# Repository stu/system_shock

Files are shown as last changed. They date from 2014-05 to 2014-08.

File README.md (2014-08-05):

System Shock
============
System Shock is an Open Source Pinball controller system consisting of hardware schematics and source code to drive the system.

The design goal is a board set capable of;

* 128 switches
* 32 solenoids / flashers
* LCD display
* Stero Sound

The last two can be achieved by utilising a Raspberry PI or some other small embedded computer.

Current Status
==============
*This is a very early work in progress that requires a lot more testing and design review.*

Licenses
========
### Software
All software and documentation is licensed under the GNU GPL v2
(see ./gpl-v2.txt)

### Hardware
All hardware schematics are licensed under the CERN Open Hardware License v1.2
(see cern_ohl_v_1_2.txt)

Revision History
================
### 20140805
* Tagged revision 1 of the solenoid board as I sent it to the fab to get made

### 20140605
* Rerouted solenoid driver board
* Exported gerbers + Excellon drill file for solenoid driver

### 20140524

* Expose to github
* Copy solenoid driver code and schematics over
* Hack up parts of master document into solenoid documentation

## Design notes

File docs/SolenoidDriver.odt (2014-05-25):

# Solenoid Driver

Last Edit; 20140524

## Introduction

The Solenoid driver consists of two parts, a hardware schematic in DipTrace and the software component that runs on the propeller microcontroller.

The schematic for the solenoid driver is under the CERN Open Hardware license v1.2

The source code for the solenoid driver is under the GNU GPL v2

## Hardware Overview

The goal of the solenoid is to control the high voltage power (solenoids, flashers, motors, etc). We are using the lower voltage of the microcontroller at 3.3v. We control the high power basically using an MOSFET driver (MCP1407) and an IRF640 MOSFET. This achieves low side switching (low side switching is where power (+) is continually run to the device (eg: solenoid), and when the solenoid driver closes the circuit and connects the ground (GND or -).

Low side switching as we are doing, is much easier to achieve than High side switching (where you continually connect GND and only connect the + as needed).

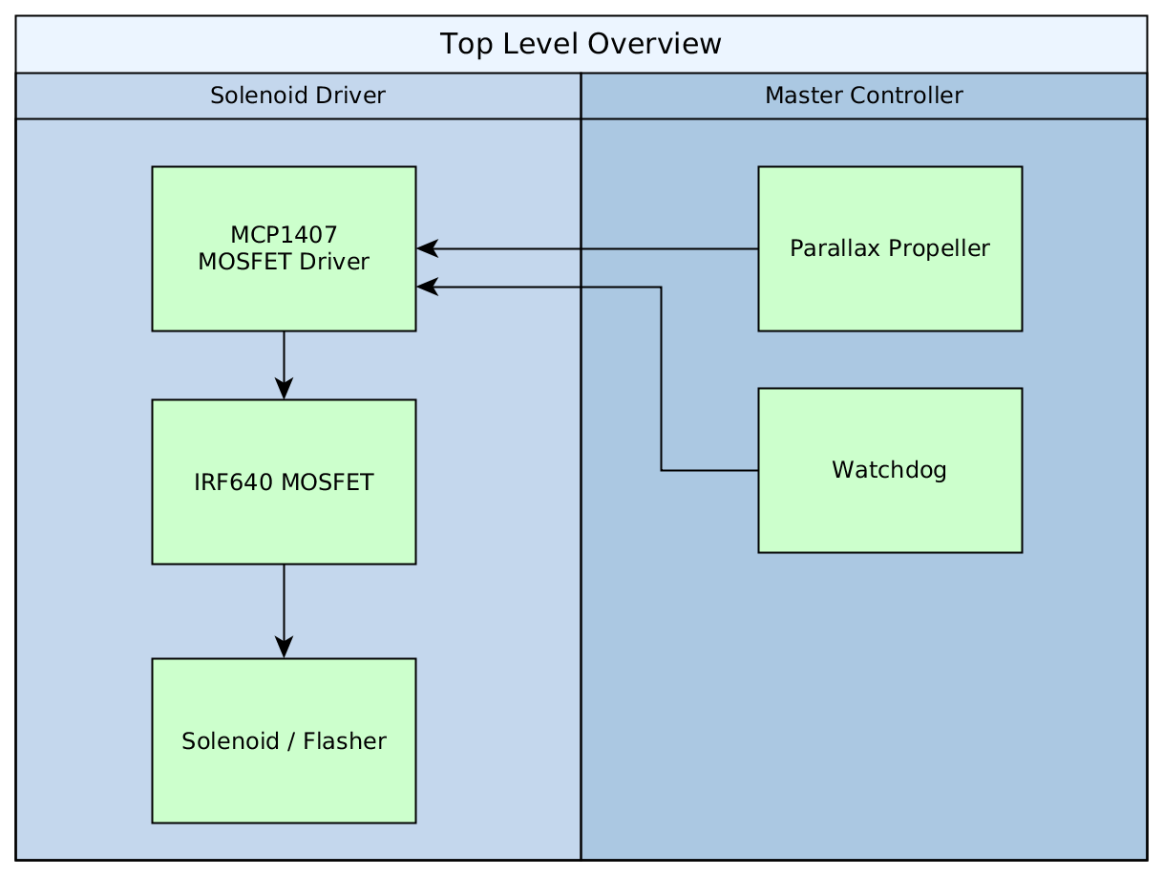
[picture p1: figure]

The propeller does the timings of all the 32 solenoids, it works in conjunction with the watchdog. The idea of the watchdog is to look over the propeller and make sure its not locked up. If the propeller locks up, the watchdog cuts off power to all the solenoids so things do not burn up and lock on.

The propeller has 8 internal cores that run simultaneously. We use core 0 to read 32 switch inputs from the Master Control board, as well as send the 32 outputs to the shift register chips that connect directly to the MOSFET Drivers. We use cores 1 thru 7 to do all the timings, they each time 5 solenoids, with the last timing just 2 to round us to 32 in total.

The propeller outputs to a bank of 4 shift registers, that are also tied directly to the watchdog output.

## Software

The source code has been written for compilation with the PropGCC compiler, and has been designed to run completely inside its COG memory model (As small detour, the propeller has 3 or 4 memory models that PropGCC can use, if the code is small enough to fit inside the propellers cache, it can run as COG ram, if its larger than the memory space, it will be compiled into an intermediate byte code and retrieved from its EEPROM, this takes a substantial performance hit), it is also written to be lock free.

## Power

There are two different power requirements for the solenoid driver. There is the lower voltage 3.3VDC driving the shift registers, and the higher 12VDC voltage driving the FET drivers. The FET drivers use a higher voltage to pump the MOSFET into action.

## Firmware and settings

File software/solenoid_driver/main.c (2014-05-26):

#include <propeller.h>
#include <stdint.h>
#include <sys/thread.h>

#include "solenoid.h"

struct solenoid_mailbox cogdata[7];

// configuration set over the wire by the master control board
HUBDATA volatile uint32_t initial_pulse_time_min[MAX_SOL];
HUBDATA volatile uint32_t initial_pulse_time_max[MAX_SOL];
HUBDATA volatile uint32_t pulse_pause_time[MAX_SOL];
HUBDATA volatile uint32_t pulse_hold_time[MAX_SOL];

// These change each time coils fire
HUBDATA volatile uint32_t state[MAX_SOL];
HUBDATA volatile uint32_t power_on_ms[MAX_SOL];
HUBDATA volatile uint32_t cnt_start[MAX_SOL];

// each cog gets its own variable so we can go lockless
HUBDATA volatile uint32_t solenoid_pins0;
HUBDATA volatile uint32_t solenoid_pins1;
HUBDATA volatile uint32_t solenoid_pins2;
HUBDATA volatile uint32_t solenoid_pins3;
HUBDATA volatile uint32_t solenoid_pins4;
HUBDATA volatile uint32_t solenoid_pins5;
HUBDATA volatile uint32_t solenoid_pins6;


/* cause all internal data state to reset */
#define CMD_RESET			0x01

/* This takes 4 bytes of 8bit data to setup */
#define CMD_SETUP_SOL		0x02

/* this takes 4x8bit data for 32 switch inputs */
#define CMD_SWITCHES		0x03


/*
 * These pins map as written in the data sheet.
 */

// direct message communication
#define COMMS_D1			0
#define COMMS_D2			1
#define COMMS_D3			2
#define COMMS_D4			3
#define COMMS_D5			4
#define COMMS_D6			5
#define COMMS_D7			6
#define COMMS_D8			7

#define COMMS_D9			8
#define COMMS_D10			9
#define COMMS_D11			10
#define COMMS_D12			11
#define COMMS_D13			12
#define COMMS_D14			13
#define COMMS_D15			14
#define COMMS_D16			15

#define RCV_PIN				27
#define RCV_OK				26

// solenoid outputs
#define HC595_CLK			16
#define HC595_DATA			17
#define HC595_LATCH			18
#define WATCHDOG			19

#define PIN_HIGH(a)		(OUTA |= (1 << (a)))
#define PIN_LOW(a)		(OUTA &= ~(1 << (a)))
#define READ_PIN(a)		(INA & (1 << (a)) )

/* Reads 16bits of data from PIC32 command.
 *
 * @blocking zero will wait until data arrives.
 */
static uint32_t read_command_word (int blocking)
{
	uint32_t data;

	// wait for rcv to go high for data is ready
	while (READ_PIN(RCV_PIN) == 0)
	{
		if (blocking != 0)
			return 0;
	}

	// get 16 bits and say we got it
	data = ((INA >> COMMS_D1) & 0xFFFF);
	PIN_HIGH(RCV_OK);

	// wait for RCV to go low
	while (READ_PIN(RCV_PIN) == 1)
		;

	// put OK low so we are ready for next communication
	PIN_LOW(RCV_OK);

	return data;
}

/* Resets all solenoid out data pins, and all internal data structures
 */
static void reset_data (void)
{
	int i;

	// set all pins to 0
	solenoid_pins0 = 0;
	solenoid_pins1 = 0;
	solenoid_pins2 = 0;
	solenoid_pins3 = 0;
	solenoid_pins4 = 0;
	solenoid_pins5 = 0;
	solenoid_pins6 = 0;

	// kill config
	for (i = 0; i < MAX_SOL; i++)
	{
		initial_pulse_time_min[i] = 0;
		initial_pulse_time_max[i] = 0;
		pulse_pause_time[i] = 0;
		pulse_hold_time[i] = 0;
		state[i] = STATE_NOTHING;
	}


}

/* Output all active solenoid state bits to the
 * 74HC595 chips.
 */
static void hc595_out_solenoids (void)
{
	int i;

	// preload so the cogs can write to it while we out it..
	uint32_t x = solenoid_pins0 | solenoid_pins1 | solenoid_pins2 | solenoid_pins3 | solenoid_pins4 | solenoid_pins5 | solenoid_pins6;

	// latch low so we dont SEE the data change.
	PIN_LOW(HC595_LATCH);

	for (i = 0; i < 32; i++)
	{
		if ((x & 0x80000000) == 0)
			PIN_LOW(HC595_DATA);
		else
			PIN_HIGH(HC595_DATA);

		// Pulse clock input to write next bit.
		PIN_LOW(HC595_CLK);
		PIN_HIGH(HC595_CLK);

		x = x << 1;
	}

	// latch high so data is seen!
	PIN_HIGH(HC595_LATCH);
}

int main (int argc, char *argv[])
{
	uint32_t c1;
	uint32_t switches;
	uint32_t old_switches;

	OUTA = 0;

	// inputs + outputs
#define XXOUT	(1 << RCV_OK) \
				| (1 << HC595_CLK) \
				| (1 << HC595_DATA) \
				| (1 << HC595_LATCH) \
				| (1 << WATCHDOG)


#define XXIN	(1 << RCV_PIN) \
				| (1 << COMMS_D1) \
				| (1 << COMMS_D2) \
				| (1 << COMMS_D3) \
				| (1 << COMMS_D4) \
				| (1 << COMMS_D5) \
				| (1 << COMMS_D6) \
				| (1 << COMMS_D7) \
				| (1 << COMMS_D8) \
				| (1 << COMMS_D9) \
				| (1 << COMMS_D10) \
				| (1 << COMMS_D11) \
				| (1 << COMMS_D12) \
				| (1 << COMMS_D13) \
				| (1 << COMMS_D14) \
				| (1 << COMMS_D15) \
				| (1 << COMMS_D16)

	// all output pins as 1's.
	DIRA = XXOUT;

	cognew(_load_start_sol1_cog, (void *) &cogdata[0]);
	cognew(_load_start_sol2_cog, (void *) &cogdata[1]);
	cognew(_load_start_sol3_cog, (void *) &cogdata[2]);
	cognew(_load_start_sol4_cog, (void *) &cogdata[3]);
	cognew(_load_start_sol5_cog, (void *) &cogdata[4]);
	cognew(_load_start_sol6_cog, (void *) &cogdata[5]);
	cognew(_load_start_sol7_cog, (void *) &cogdata[6]);


	// Do a reset on startup.
	c1 = CMD_RESET;
	old_switches = 0;
	switches = 0;

	while (1)
	{
		//***********************************************************************
		// heartbeat to watchdog chip transition from a high to low state.
		// We have 62ms in order to toggle the pin before reset!
		// **********************************************************************
		PIN_HIGH(WATCHDOG);
		PIN_LOW(WATCHDOG);

		switch (c1)
		{
			case CMD_RESET:
				reset_data();
				old_switches = 0;
				hc595_out_solenoids();
				// wait 2 seconds
				waitcnt(ONE_SEC * 2);
				break;

			case CMD_SETUP_SOL:
				c1 = read_command_word(0); // solenoid in 16bits

				initial_pulse_time_min[c1] = ONE_MS * read_command_word(0);
				initial_pulse_time_max[c1] = ONE_MS * read_command_word(0);
				pulse_pause_time[c1] = ONE_MS * read_command_word(0);
				pulse_hold_time[c1] = ONE_MS * read_command_word(0);
				break;

			case CMD_SWITCHES:
				switches = (read_command_word(0) << 16) | (read_command_word(0));
				break;

				// traps the non message command for non blocking (-1)
			default:
				switches = old_switches;
				break;
		}

		// output the current soelnoid state for on/off
		hc595_out_solenoids();

		// need to compare it against last trigger?? if difference
		// if it its, KAPOW BLAM
		for (c1 = 0; c1 < 32; c1++)
		{
			// SWITCH is ON = FIRE
			if ((switches & (1 << c1)) != 0)
			{
				// previous switch was OFF so FIRE
				if ((old_switches & (1 << c1)) == 0)
				{
					state[c1] = STATE_FIRE;
				}
				else
				{
					// previous switch was on, its still pressed. dont change
				}
			}
			else
			{
				// switch is now off
				state[c1] = STATE_NOTHING;
			}
		}

		// store the old info
		old_switches = switches;

		//waitcnt(ONE_MS);

		// look for a command, non blocking!
		// if no command, put current switch set now in old_d1 back into d1
		c1 = read_command_word(1);
	}
}

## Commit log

2014-05-25 Initial push of solenoid driver code/docs
2014-05-26 Fix conversion of count to milliseconds
    [main.c]
2014-06-06 Rerouted solenoid board, and added gerbers with excellon drill
    [solenoid_fets.gbl, solenoid_fets.gbo, solenoid_fets.gbs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]
2014-08-05 Rev 1 gerbers of the solenoid driver board
    [solenoid_fets.gbl, solenoid_fets.gbo, solenoid_fets.gbs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]
